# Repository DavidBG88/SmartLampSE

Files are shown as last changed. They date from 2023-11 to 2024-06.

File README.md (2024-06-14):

# **SmartLampSE**

## **Overview**
This repository contains the code for the Smart Lamp EmbeddedSystem (SmartLampSE) project. The project involves designing and implementing a smart lamp system using various technologies and programming languages.

## **Features**
- **Electronics Design**: Schematics and PCB design for the smart lamp hardware.
- **Software**: Code for controlling the smart lamp, including firmware and higher-level software.
- **System Model**: Models and diagrams illustrating the system architecture and behavior.

## **Structure**
- **electronics_design/**: Contains schematics and PCB design files.
- **software/**: Source code for the smart lamp, including firmware and application software.
- **system_model/**: System architecture models and documentation.
- **.gitignore**: Git ignore file for the repository.

## **Contributors**
- [DavidBG88](https://github.com/DavidBG88)
- [Tikitikitikidesuka](https://github.com/Tikitikitikidesuka)

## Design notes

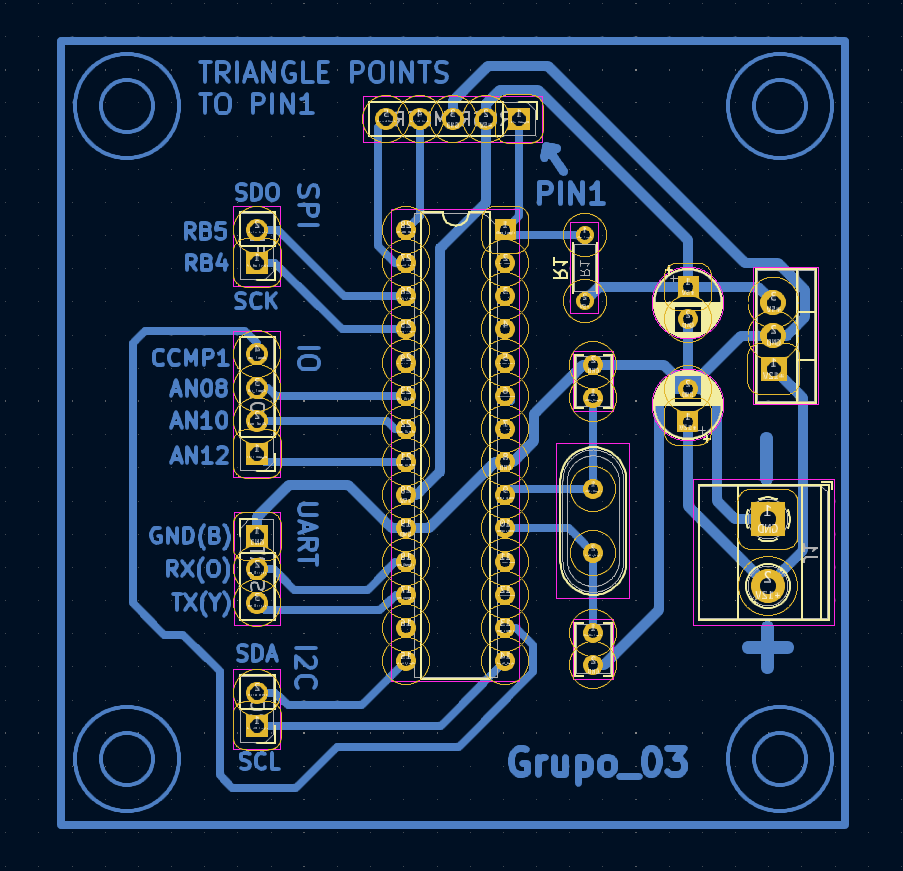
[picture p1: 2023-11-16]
electronics_design/Design.png

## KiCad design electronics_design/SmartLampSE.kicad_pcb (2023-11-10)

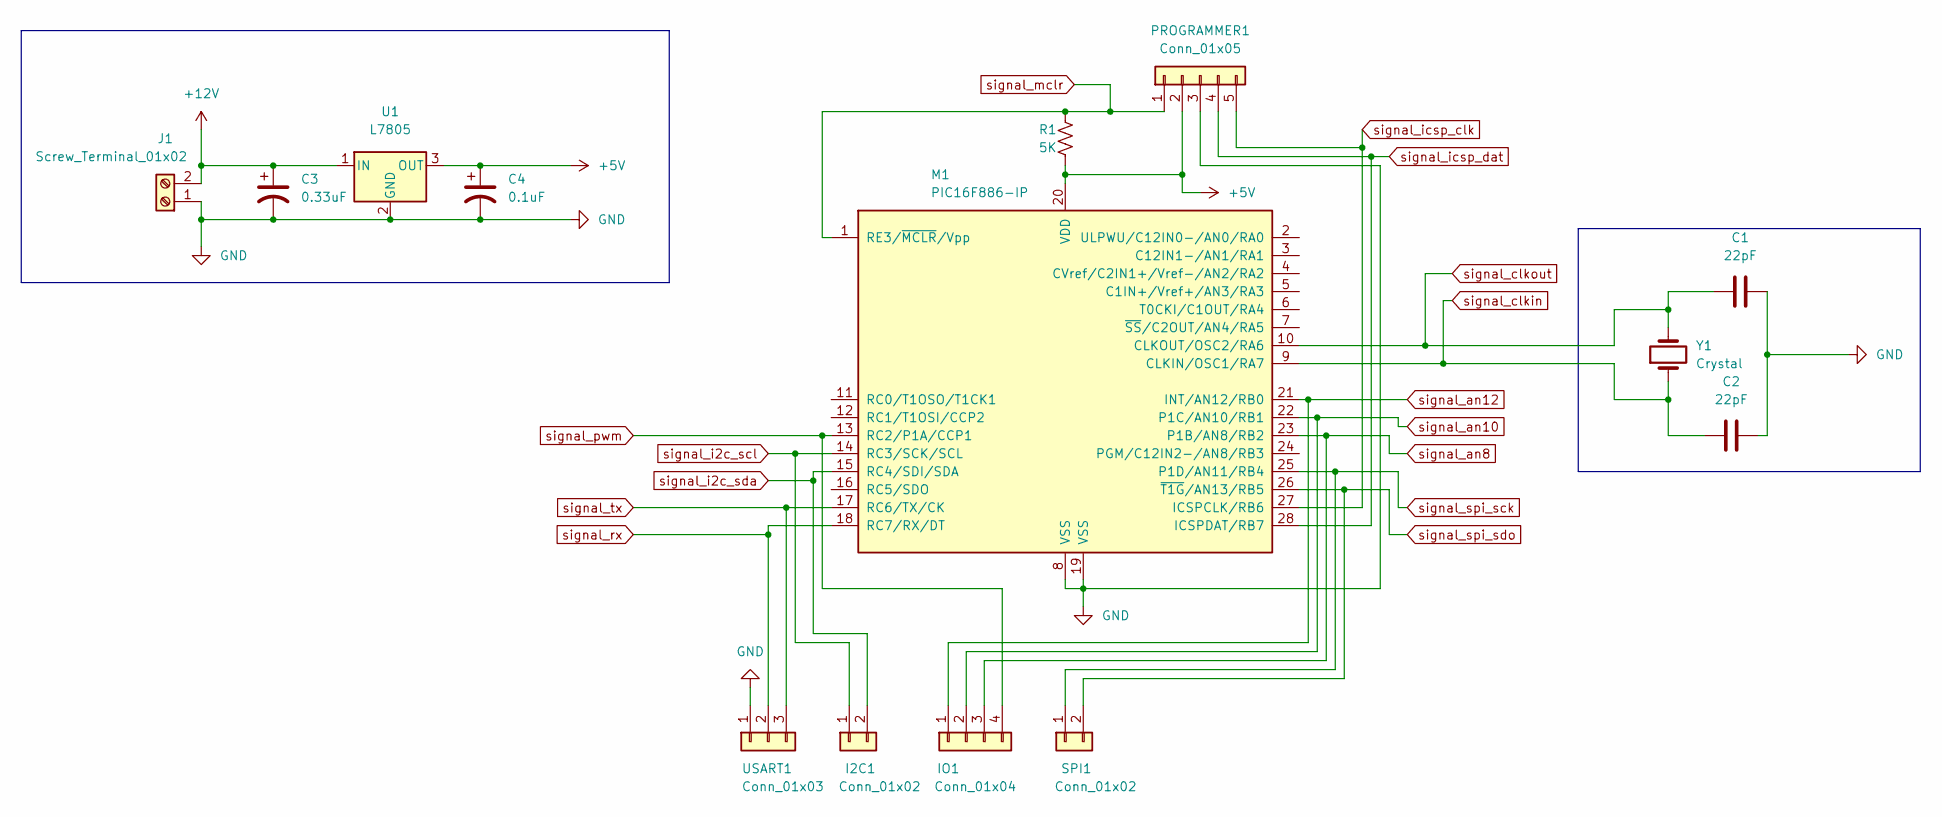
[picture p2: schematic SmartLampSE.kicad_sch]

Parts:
C1, C2: 22pF; C_Disc_D3.8mm_W2.6mm_P2.50mm
C3: 0.33uF; CP_Radial_D5.0mm_P2.50mm
C4: 0.1uF; CP_Radial_D5.0mm_P2.50mm
I2C1: Conn_01x02; PinSocket_1x02_P2.54mm_Vertical
IO1: Conn_01x04; PinSocket_1x04_P2.54mm_Vertical
J1: Screw_Terminal_01x02; TerminalBlock_Phoenix_MKDS-1,5-2-5.08_1x02_P5.08mm_Horizont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
M1: PIC16F886-IP; DIP-28_W7.62mm
PROGRAMMER1: Conn_01x05; PinSocket_1x05_P2.54mm_Vertical
R1: 5K; R_Axial_DIN0204_L3.6mm_D1.6mm_P5.08mm_Horizontal
SPI1: Conn_01x02; PinSocket_1x02_P2.54mm_Vertical
U1: L7805; TO-220-3_Vertical
USART1: Conn_01x03; PinSocket_1x03_P2.54mm_Vertical
Y1: Crystal; Crystal_HC18-U_Vertical

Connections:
+5V: C4.1, M1.20 (VDD), PROGRAMMER1.2, R1.2, U1.3 (OUT)
+12V: C3.1, J1.2, U1.1 (IN)
GND: C1.2, C2.2, C3.2, C4.2, J1.1, M1.8 (VSS), M1.19 (VSS), PROGRAMMER1.3, U1.2 (GND), USART1.1
signal_an8: IO1.3, M1.23 (P1B/AN8/RB2)
signal_an10: IO1.2, M1.22 (P1C/AN10/RB1)
signal_an12: IO1.1, M1.21 (INT/AN12/RB0)
signal_clkin: C2.1, M1.9 (CLKIN/OSC1/RA7), Y1.1
signal_clkout: C1.1, M1.10 (CLKOUT/OSC2/RA6), Y1.2
signal_i2c_scl: I2C1.1, M1.14 (RC3/SCK/SCL)
signal_i2c_sda: I2C1.2, M1.15 (RC4/SDI/SDA)
signal_icsp_clk: M1.27 (ICSPCLK/RB6), PROGRAMMER1.5
signal_icsp_dat: M1.28 (ICSPDAT/RB7), PROGRAMMER1.4
signal_mclr: M1.1 (RE3/~MCLR/Vpp), PROGRAMMER1.1, R1.1
signal_pwm: IO1.4, M1.13 (RC2/P1A/CCP1)
signal_rx: M1.18 (RC7/RX/DT), USART1.2
signal_spi_sck: M1.25 (P1D/AN11/RB4), SPI1.1
signal_spi_sdo: M1.26 (~T1G/AN13/RB5), SPI1.2
signal_tx: M1.17 (RC6/TX/CK), USART1.3

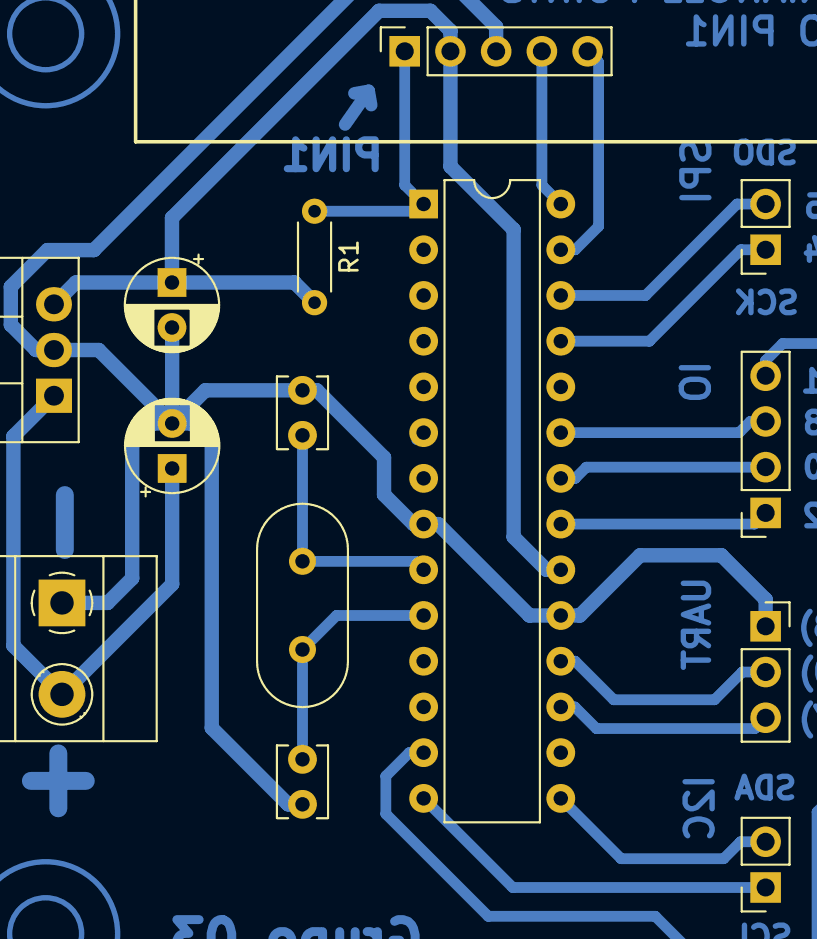
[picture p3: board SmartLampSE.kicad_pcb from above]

Board: 2 copper layers, 14 parts (0 on the bottom side), 18 nets.

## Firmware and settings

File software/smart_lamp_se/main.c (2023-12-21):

#pragma config CPD = OFF, BOREN = OFF, IESO = OFF, DEBUG = OFF, FOSC = HS
#pragma config FCMEN = OFF, MCLRE = ON, WDTE = OFF, CP = OFF, LVP = OFF
#pragma config PWRTE = ON, BOR4V = BOR21V, WRT = OFF

#pragma intrinsic(_delay)
#define _XTAL_FREQ 20000000  // necessary for __delay_us

#include <stdio.h>
#include <stdlib.h>

#include <xc.h>

#include "APA102.h"
#include "HIH4000.h"
#include "LM35.h"
#include "VEML7700.h"
#include "adc.h"
#include "eeprom.h"
#include "iAQCore.h"
#include "pwm.h"
#include "i2c.h"
#include "spi.h"
#include "timing.h"
#include "uart.h"

#define NUM_LEDS 10
#define SOUND_BUFFER_SIZE 100

#define SOUND_ADC_PIN ADC0
#define TEMPERATURE_ADC_PIN ADC1
#define HUMIDITY_ADC_PIN ADC1

#define UART_CO2_TX_CODE 0
#define UART_HUMIDITY_TX_CODE 1
#define UART_TEMPERATURE_TX_CODE 2
#define UART_SOUND_TX_CODE 3
#define UART_LIGHT_TX_CODE 4

#define UART_LIGHT_RX_CODE 0
#define UART_FAN_RX_CODE 1

#define CONFIG_MEM_CONTROL 0b01010101
#define CONFIG_MEM_CONTROL_ADDR 0x0
#define LIGHT_P_MEM_ADDR 0x1
#define LIGHT_R_MEM_ADDR 0x2
#define LIGHT_G_MEM_ADDR 0x3
#define LIGHT_B_MEM_ADDR 0x4
#define FAN_SPEED_MEM_ADDR 0X5

#define DEFAULT_FAN_SPEED 0
#define DEFAULT_P_LIGHT 16
#define DEFAULT_R_LIGHT 255
#define DEFAULT_G_LIGHT 255
#define DEFAULT_B_LIGHT 255

uint16_t max_sound = 0;

void record_sound_level(void) {
    uint16_t read_sound = ADC_read(SOUND_ADC_PIN);

    if (read_sound > max_sound)
        max_sound = read_sound;
}

void send_sound_level(void) {
    uint8_t message_bytes[] = {UART_SOUND_TX_CODE, ((uint8_t*)&max_sound)[1],
                               ((uint8_t*)&max_sound)[0]};

    UART_write_n_bytes(message_bytes, 3);

    max_sound = 0;
}

void record_and_send_co2_data(void) {
    IAQCORE_Reading reading = IAQCORE_read();

    uint8_t message_bytes[] = {UART_CO2_TX_CODE, ((uint8_t*)&reading.eco2_ppm)[1],
                               ((uint8_t*)&reading.eco2_ppm)[0]};
                               
    UART_write_n_bytes(message_bytes, 3);
}

void record_and_send_temperature(void) {
    uint16_t temp = LM35_read_celsius(TEMPERATURE_ADC_PIN);

    uint8_t message_bytes[] = {UART_TEMPERATURE_TX_CODE, (uint8_t)(temp >> 8), (uint8_t)temp};
    //uint8_t message_bytes[] = {UART_TEMPERATURE_TX_CODE, 10, 10};

    UART_write_n_bytes(message_bytes, 3);
}

void record_and_send_light_lux(void) {
    uint16_t lux = VEML7700_read_light_lux();

    uint8_t message_bytes[] = {UART_LIGHT_TX_CODE, (uint8_t)(lux >> 8), (uint8_t)lux};
    //uint8_t message_bytes[] = {UART_LIGHT_TX_CODE, 10, 10};

    UART_write_n_bytes(message_bytes, 3);
}

void record_and_send_humidity(void) {
    uint16_t humidity = HIH4000_read_humidity(HUMIDITY_ADC_PIN, LM35_read_celsius(TEMPERATURE_ADC_PIN));

    uint8_t message_bytes[] = {UART_HUMIDITY_TX_CODE, (uint8_t)(humidity >> 8), (uint8_t)humidity};
    //uint8_t message_bytes[] = {UART_HUMIDITY_TX_CODE, 10, 10};

    UART_write_n_bytes(message_bytes, 3);
}

void record_and_send_environment_data(void) {
    record_and_send_co2_data();
    record_and_send_temperature();
    record_and_send_light_lux();
    record_and_send_humidity();
}

void update_light(uint8_t p, uint8_t r, uint8_t g, uint8_t b) {
    APA102_set_color(p, r, g, b);
}

void update_fan_speed(uint8_t speed) {
    PWM_set_duty_cycle((uint16_t)(PWM_get_max_duty_cycle() * (uint32_t)speed / 255));
}

void report_invalid_command(uint8_t command) {
    // NO INVALID COMMAND REPORT PROTOCOL SPECIFIED
}

void match_incomming_uart_command(void) {
    /*
    | Dato       | Codigo | Tipo                                 |
    | ---------- | ------ | ------------------------------------ |
    | Luz        | 0      | (uint8_t, uint8_t, uint8_t, uint8_t) |
    | Ventilador | 1      | uint8_t                              |
    */

    uint8_t command = UART_read_byte();

    switch (command) {
        case UART_LIGHT_RX_CODE: {  // Light
            uint8_t prgb[4];
            UART_read_n_bytes(prgb, sizeof(prgb));
            update_light(prgb[0], prgb[1], prgb[2], prgb[3]);
            EEPROM_write(LIGHT_P_MEM_ADDR, prgb[0]);
            EEPROM_write(LIGHT_R_MEM_ADDR, prgb[1]);
            EEPROM_write(LIGHT_G_MEM_ADDR, prgb[2]);
            EEPROM_write(LIGHT_B_MEM_ADDR, prgb[3]);
            break;
        }
        case UART_FAN_RX_CODE: {  // Fan speed
            uint8_t speed;
            UART_read_n_bytes(&speed, sizeof(speed));
            update_fan_speed(speed);
            EEPROM_write(FAN_SPEED_MEM_ADDR, speed);
            break;
        }
        default:
            //report_invalid_command(command);
            break;
    }
}

inline bool prev_conf_exists() {
    return EEPROM_read(CONFIG_MEM_CONTROL_ADDR) == CONFIG_MEM_CONTROL;
}

int main(void) {
    // Enable interrupts
    INTCONbits.GIE = 1;   // Enable interrupts
    INTCONbits.PEIE = 1;  // Enable peripheral interrupts
    INTCONbits.T0IE = 1;  // Enable Timer0 interrupts

    uint8_t fan_speed;
    uint8_t p, r, g, b;

    if (!prev_conf_exists()) {
        EEPROM_write(LIGHT_P_MEM_ADDR, DEFAULT_P_LIGHT);
        EEPROM_write(LIGHT_R_MEM_ADDR, DEFAULT_R_LIGHT);
        EEPROM_write(LIGHT_G_MEM_ADDR, DEFAULT_G_LIGHT);
        EEPROM_write(LIGHT_B_MEM_ADDR, DEFAULT_B_LIGHT);
        EEPROM_write(FAN_SPEED_MEM_ADDR, DEFAULT_FAN_SPEED);
        EEPROM_write(CONFIG_MEM_CONTROL_ADDR, CONFIG_MEM_CONTROL);
    }

    p = EEPROM_read(LIGHT_P_MEM_ADDR);
    r = EEPROM_read(LIGHT_R_MEM_ADDR);
    g = EEPROM_read(LIGHT_G_MEM_ADDR);
    b = EEPROM_read(LIGHT_B_MEM_ADDR);
    fan_speed = EEPROM_read(FAN_SPEED_MEM_ADDR);
    
    // Initialize I2C and SPI
    SPI_init();
    I2C_init();

    // Initialize ADC
    ADC_init();

    // Initialize iAQCore sensor
    IAQCORE_init();

    // Initialize APA102 light strip
    APA102_init(NUM_LEDS);

    // Initialize PWM
    PWM_init();
    PWM_set_period(255, 0);
    PWM_set_duty_cycle(0);

    // Initialize timing
    TIMING_init();
    TIMING_set_tick_duration(256 - 250, PR1to8);  // Tick = 1.6us * 250 = 400us

    // Set timing callbacks
    TIMING_run_every_n_ticks(25, record_sound_level);  // Every 10ms   -> 25 ticks
    TIMING_run_every_n_ticks(2500, send_sound_level);  // Every 1000ms -> 2500 ticks
    TIMING_run_every_n_ticks(12500,
                             record_and_send_environment_data);  // Every 5000ms -> 12500 ticks

    // Initialize UART
    UART_init();
    UART_set_baud_rate(32);  // 9600 bauds / sec
    PIE1bits.RCIE = 1;       // Enable RX interrupt

    update_fan_speed(fan_speed);
    update_light(p, r, g, b);
    
    while (1) {
        //SLEEP();
        //NOP();
    }

    return (EXIT_SUCCESS);
}

void __interrupt() interrupt_handler(void) {
    if (PIR1bits.RCIF) {
        // ECHO BACK UART FOR TESTING
        //uint8_t input_byte = UART_read_byte();
        //UART_write_byte(input_byte);

        match_incomming_uart_command();
        PIR1bits.RCIF = 0;
    } else if (PIR1bits.TMR2IF) {
        PWM_tmr2_interrupt_handler();
        PIR1bits.TMR2IF = 0;
    } else if (INTCONbits.T0IF) {
        TIMING_tmr0_interrupt_handler();
        INTCONbits.T0IF = 0;
    }
}

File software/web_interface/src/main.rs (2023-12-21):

use serialport::SerialPort;
use crate::api::api_routes;
use crate::model::model::ServerModel;

mod api;
mod model;

#[tokio::main]
async fn main() {
    let server_model: ServerModel = ServerModel::new();
    let app = api_routes::routes(server_model.clone());
    let listener = tokio::net::TcpListener::bind("localhost:3000").await.unwrap();
    axum::serve(listener, app).await.unwrap();
}

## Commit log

2023-11-06 Separate board IO interface
    [SmartLampSE.kicad_pcb, SmartLampSE.kicad_sch]
2023-11-06 Finish pcb pathing
    [SmartLampSE.kicad_pcb]
2023-11-07 Update group name on electronics design
    [SmartLampSE.kicad_pcb]
2023-11-09 Add visual polarity indicators to board supply
    [SmartLampSE.kicad_pcb]
2023-11-10 Fix some widths
    [SmartLampSE.kicad_pcb]
2023-11-11 Update pwm library
2023-11-16 Fix typos in pwm header file
2023-11-16 Remove board test libraries
2023-11-16 Added tests to main.c for ADC and USART, also notes for I2C future tests
2023-11-22 Add ADC module
2023-11-22 Fix adc type warning
    [adc.c]
2023-11-22 Add uart module
2023-11-30 Update uart library
2023-12-01 Fix uart last byte missing error
    [uart.c]
2023-12-01 Update interrupt flag update policy
2023-12-01 Added I2C test to board_test
2023-12-01 Update uart module
2023-12-01 Update UART to remove unnecessary code
2023-12-03 Add i2c library
2023-12-03 Add library for the iAQ-Core sensor
2023-12-03 Update implicit conversion in i2c.c
2023-12-03 Add spi library
2023-12-03 Add APA102 RGB LED library
2023-12-03 Update ADC module to take adc pin as parameter
2023-12-03 Add i2c init function
2023-12-03 Fix missing void in function parameters
    [APA102.c, adc.c, main.c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]
2023-12-03 Rename ADC methods as part of a general refactor
2023-12-03 Fix repeated function name in adc module
    [adc.c]
2023-12-03 Rename i2c methods as part of a general refactor
2023-12-03 Rename PWM methods as part of a general refactor
2023-12-03 Rename SPI methods as part of a general refactor
2023-12-03 Rename UART methods as part of a general refactor
2023-12-04 Add uart tx test source files
2023-12-04 Major refactor to board test project
2023-12-04 Fill in pwm, uart rx and uart tx tests
2023-12-04 Fix missing start and end frame in APA102 library
    [APA102.c]
2023-12-08 Upgrade web interface to show sensor values
2023-12-14 Add detailed UARt Activity Diagrams
2023-12-14 Add PWM detailed Activity Diagrams
2023-12-14 Add ADC detailed Activity Diagrams
2023-12-20 Fix actuator commands
2023-12-20 Fix mismatch typo on I2C_restart header
    [i2c.h]
2023-12-20 Add new sensor libraries to main project
2023-12-21 Move ADC VREF and RESOLUTION constants to adc.h
2023-12-21 Add read_n_bytes_reverse function to i2c module
2023-12-21 Fix pwm to return correct max duty cycle value
    [pwm.c]
2023-12-21 Fix incorrect endianness in i2c iAQ-Core sensor reading
    [iAQCore.c]
2023-12-21 Update spi module mode
2023-12-21 Update uart module mode
2023-12-21 Fix sound transform in web gui
    [api_routes.rs]
2023-12-21 Update sma-lamp board test libraries to match the ones in smart_lamp_se
